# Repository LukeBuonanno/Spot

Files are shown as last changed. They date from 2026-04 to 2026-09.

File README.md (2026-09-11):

# ESP32-S3 Spotify Controller (GC9A01 Round TFT)

A handheld Spotify controller using an ESP32-S3, a 1.28" round GC9A01 TFT display, and a 4-button module, all housed in a 3D-printed chassis with a Windows 98–style interface.

## Notes

* This device controls Spotify playback but does not output audio
* Requires an active Spotify session on another device
* Spotify Premium is required for API playback control

## Hardware Requirements

* ESP32-S3 Dev Board
* 1.28" Round TFT LCD Display (240x240, GC9A01 driver)
* 4-bit Independent Button Module (micro switch board)
* Jumper wires
* 3D printed chassis
* USB cable for power and programming

Printables link: https://www.printables.com/model/1770463-spotify-controller-chassy

## Physical Assembly

### 1. Install the Display

* Press the round TFT display into the front ring of the chassis
* Ensure it sits flush and centered

### 2. Wire the Display (SPI)

Connect the display to the ESP32-S3 as follows:

| Display Pin | ESP32-S3 Pin |
| --- | --- |
| VCC | 3.3V |
| GND | GND |
| SCL (CLK) | GPIO 36 |
| SDA (MOSI)  | GPIO 35 |
| DC | GPIO 12 |
| CS | GPIO 14 |
| RST | GPIO 13 |

### 4. Wire the Button Module

The 4-button module typically has:

* VCC
* GND
* 4 signal outputs (one per button)

Connect as follows:

| Button Function | ESP32 Pin |
| --- | --- |
| Play/Pause | GPIO 4 |
| Mode/Menu | GPIO 5 |
| Previous | GPIO 6 |
| Next | GPIO 7 |

Then:

* Connect **GND on the module → ESP32 GND**
* If the module requires power:

  * Connect **VCC → 3.3V**

### 5. Final step: Install the ESP32-S3

* Insert the ESP32-S3 into the back of the chassis with pins facing inward.
* Connect USB power

## Software Setup

### 1. Install Arduino IDE

Install the latest Arduino IDE.

### 2. Install ESP32 Board Package

In Arduino IDE:

File → Preferences → Additional Board URLs:

https://raw.githubusercontent.com/espressif/arduino-esp32/gh-pages/package_esp32_index.json

Then:

* Open Boards Manager
* Install "ESP32 by Espressif Systems"

### 3. Select Board

* Board: ESP32S3 Dev Module
* Select the correct COM port

### 4. Install Required Libraries

Install these from Library Manager:

* ArduinoJson
* Adafruit GFX
* Adafruit GC9A01A

### 5. Add Project Files

Place these files in your project folder:

* micross7pt7b.h
* win98_clouds.h
* warning.h
* stop.h

## Spotify Setup

### 1. Create a Spotify App

Go to the Spotify Developer Dashboard and create an app.

You will get:

* Client ID
* Client Secret

### 2. Generate Refresh Token

Use OAuth with scopes:

user-read-playback-state
user-modify-playback-state

### 3. Insert Credentials

Update in your code:

String clientId = "YOUR_CLIENT_ID";
String clientSecret = "YOUR_CLIENT_SECRET";
String refreshToken = "YOUR_REFRESH_TOKEN";

## Uploading the Code

1. Connect ESP32-S3 via USB
2. Select correct board and port
3. Click Upload

If upload fails:

* Hold the BOOT button while uploading

## WiFi Setup
On first boot, the device creates a WiFi network:
Spotify-Controller-Setup

Join that network from your phone or laptop
Open: http://192.168.4.1

Input your WiFi name + password
Click Save and connect!

## Controls
(From left to right)
| Button | Action |
| --- | --- |
| Previous | Previous track |
| Next | Next track |
| Play | Play / Pause |
| Mode | Open playlist menu |

## Playlist Menu

* Previous / Next: Navigate playlists
* Play: Select playlist
* Mode: Exit menu

## Troubleshooting

### Screen not working

* Verify SPI wiring (SCL, SDA, CS, DC, RST)
* Confirm pins match code

### Spotify not responding

* Ensure a device is actively playing (phone, computer, etc.)
* Verify token and credentials

### Error screen appears

* No active Spotify device
* WiFi or API connection issue

### Buttons not working

* Check wiring from module outputs to GPIO pins
* Ensure GND is connected
* Confirm module logic matches pull-up configuration

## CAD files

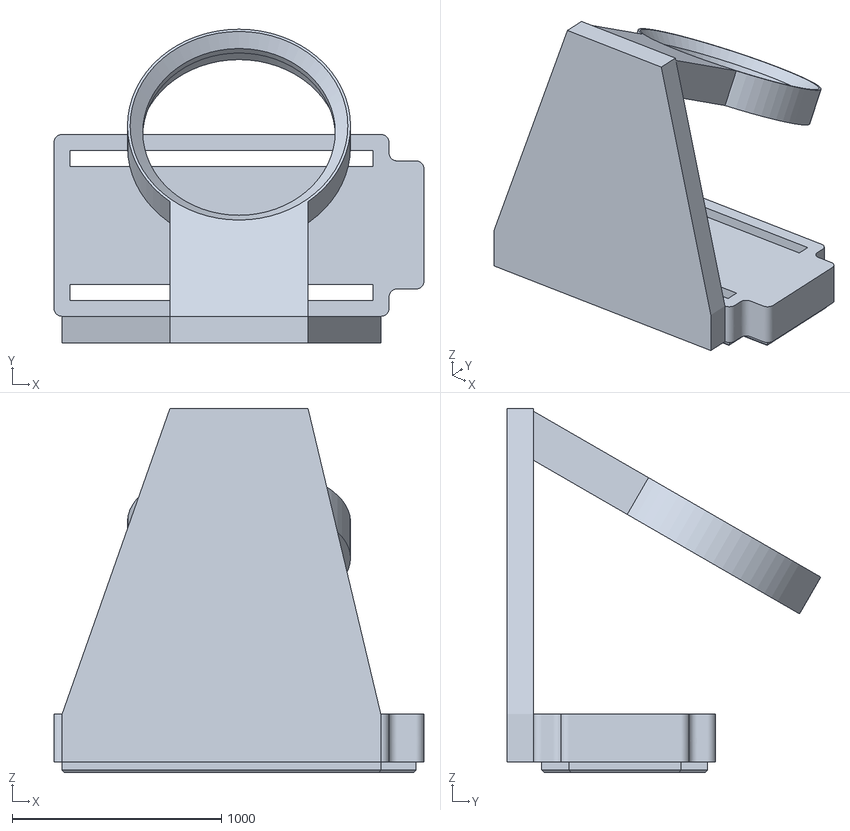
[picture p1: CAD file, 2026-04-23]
Spotify Dock.stl
1769.8 x 1500.2 x 1742.6

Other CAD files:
Spotify Dock.ipt

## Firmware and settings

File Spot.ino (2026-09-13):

#include <WiFi.h>
#include <WebServer.h>
#include <DNSServer.h>
#include <Preferences.h>
#include <WiFiClientSecure.h>
#include <HTTPClient.h>
#include <ArduinoJson.h>
#include <vector>
#include <SPI.h>
#include <Adafruit_GFX.h>
#include <Adafruit_GC9A01A.h>
#include "micross7pt7b.h"
#include "win98_clouds.h"
#include "warning.h"
#include "stop.h"

// ====== WiFi Configuration ======
// Credentials are stored permanently in ESP32 NVS using Preferences.
// The setup AP remains available while STA mode repeatedly attempts to connect.
const char* SETUP_AP_SSID = "Spotify-Controller-Setup";
const byte DNS_PORT = 53;
IPAddress setupIP(192, 168, 4, 1);

Preferences wifiPrefs;
WebServer setupServer(80);
DNSServer dnsServer;

String savedSSID = "";
String savedPassword = "";
bool wifiAttemptInProgress = false;
bool wifiWasConnected = false;
bool portalStarted = false;
unsigned long lastWifiRetry = 0;

// How long to let one WiFi.begin() attempt run before restarting it.
const unsigned long WIFI_CONNECT_TIMEOUT_MS = 15000;

// Small delay between failed attempts.
const unsigned long WIFI_RETRY_DELAY_MS = 1000;
const unsigned long WIFI_RETRY_MS = 5000;

// ====== Spotify ======
String clientId     = "CHANGEME";
String clientSecret = "CHANGEME";
String refreshToken = "CHANGEME";
String accessToken  = "";
String activeDeviceId = "";
bool isPaused  = false;
bool inMenu    = false;
int  selectedIndex = 0;

// ====== Spotify API ======
const char* spotifyAPI = "https://api.spotify.com/v1";

// ====== Buttons ======
#define BTN_MODE 5
#define BTN_PLAY 4
#define BTN_PV   6
#define BTN_NV   7

bool prevPVState   = HIGH, prevNVState   = HIGH;
bool prevPlayState = HIGH, prevModeState = HIGH;
const unsigned long LONG_PRESS_MS = 600;
const unsigned long DEBOUNCE_MS   = 50;
unsigned long lastPVAction = 0, lastNVAction = 0;
unsigned long lastPlayAction = 0, lastModeAction = 0;

// ====== Playlist ======
struct Playlist { String name; String uri; };
Playlist playlists[] = {
  {"CHANGEME (name)",       "spotify:playlist:CHANGEME"},
{"CHANGEME (name)",       "spotify:playlist:CHANGEME"},
{"CHANGEME (name)",       "spotify:playlist:CHANGEME"},
{"CHANGEME (name)",       "spotify:playlist:CHANGEME"}
};
const int NUM_PLAYLISTS = sizeof(playlists) / sizeof(playlists[0]);

// ====== TFT ======
#define TFT_MOSI 35
#define TFT_SCLK 36
#define TFT_DC   12
#define TFT_CS   14
#define TFT_RST  13
Adafruit_GC9A01A tft(TFT_CS, TFT_DC, TFT_MOSI, TFT_SCLK, TFT_RST);

inline void resetFont() {
  tft.setFont(&micross7pt7b);
  tft.setTextSize(1);
}

// ====== Win98 Color Palette ======
#define WIN98_BG     0xC618
#define WIN98_GRAY   0x9CF3
#define WIN98_DKGRAY 0x7BEF
#define WIN98_WHITE  0xFFFF
#define WIN98_BLACK  0x0000
#define WIN98_BLUE   0x001F
#define WIN98_TEXT   0x0000
#define WIN98_BORDER 0xFFFF
#define WIN98_SHADOW 0x7BEF

// ====== Window Geometry (shared constants) ======
// Keeping these as constants avoids recomputing them every draw call.
const int WIN_MARGIN   = 36;
const int WIN_TITLEBAR = 24;
const int WIN_X = WIN_MARGIN;
const int WIN_Y = WIN_MARGIN;
const int WIN_W = 240 - WIN_MARGIN * 2;   // 168
const int WIN_H = 240 - WIN_MARGIN * 2;   // 168

// ====== App State Machine ======
// These states gate both what runs in loop() AND what gets drawn to the screen.
// The screen only redraws when appState actually changes.
enum AppState {
  APP_WIFI_CONNECTING,  // STA is trying to reach the saved WiFi network
  APP_SPOTIFY_INIT,     // WiFi is up — getting token + devices
  APP_RUNNING           // fully operational, normal Spotify UI
};
AppState appState          = APP_WIFI_CONNECTING;
AppState lastDrawnAppState = (AppState)(-1);  // sentinel — forces first status draw

unsigned long lastSpotifyRetry = 0;
const unsigned long SPOTIFY_RETRY_MS = 5000;

// ====== Now Playing ======
struct NowPlaying {
  String track, artist;
  unsigned long progress_ms, duration_ms;
  bool isPlaying;
};
NowPlaying nowPlaying;

String lastTrack  = "";
String lastArtist = "";
unsigned long lastDuration = 0;
unsigned long lastProgress = 0;

// ====== Device / display state ======
bool deviceActive        = false;
bool brokenLinkDrawn     = false;
bool firstNowPlayingDraw = true;
unsigned long lastDeviceAttempt  = 0;
const unsigned long deviceRetryInterval = 5000;

// ====== Timing ======
unsigned long lastNowPlaying    = 0;
const unsigned long nowPlayingInterval = 2000;
unsigned long lastDisplayUpdate = 0;
const unsigned long displayInterval    = 150;
unsigned long lastTokenRefresh  = 0;
const unsigned long TOKEN_REFRESH_INTERVAL = 3500UL * 1000;

// ====== Display Constants ======
const int16_t DISP_W       = 240;
const int16_t DISP_H       = 240;
const int16_t BASE_TITLE_Y  = 60;
const int16_t BASE_ARTIST_Y = 90;

// ====== Forward Declarations ======
bool   refreshAccessToken();
void   fetchDevices();
void   fetchNowPlaying();
void   togglePlayPause();
void   nextTrack();
void   previousTrack();
void   playPlaylist(String uri);
void   checkButtons(unsigned long now);
void   displayNowPlaying(bool forceBG, bool forceGUI);
void   drawPlaylistMenu(bool fullRedraw, int prevIndex, int newIndex);
void   drawWin98WindowFrame(const char* title);
void   drawWin98CloudsBG();
void   drawBrokenLink(int16_t x, int16_t y);
void   drawWin98ProgressBar(unsigned long progress, unsigned long total, int y);
void   drawStatusWindow(const char* title, const char* line1, const char* line2 = "");
void   drawCenteredText(int16_t cx, int16_t cy, const char* text, uint16_t color, uint16_t bgColor);
void   drawCenteredTextBlock(int16_t cx, int16_t cy, const char* text, uint16_t color, uint16_t bgColor);
void   draw3DBorder(int x, int y, int w, int h);
void   drawWin98Button(int x, int y, int w, int h, const char* label, bool pressed = false);
void   drawWin98ButtonEx(int x, int y, int w, int h, const char* label, uint16_t bg, uint16_t textCol, bool pressed = false);
String trimString(const String& str);
int16_t getTextWidth(const String& text);
int16_t getTextHeight();
std::vector<String> wrapText(String text, int maxChars);
void loadWiFiCredentials();
void saveWiFiCredentials(const String& ssid, const String& password);
void startWiFiSetupPortal();
void handleWiFiSetupPortal();
void attemptWiFiConnection();
void handleWiFiConnection();
void setupPortalRoot();
void setupPortalSave();
void setupPortalNotFound();

// ====== Status Window ======
// Draw a Win98 window with one or two lines of centered status text.
// Touches only the window area — clouds behind it are never disturbed.
// Call this ONCE when entering a new state; it will NOT be called again
// until appState changes (enforced by the lastDrawnAppState guard in loop).
void drawStatusWindow(const char* title, const char* line1, const char* line2) {
  resetFont();
  drawWin98WindowFrame(title);  // fills WIN98_BG inside the window automatically
  if (strlen(line1) > 0)
    drawCenteredText(DISP_W / 2, DISP_H / 2 - 12, line1, WIN98_TEXT,   WIN98_BG);
  if (strlen(line2) > 0)
    drawCenteredText(DISP_W / 2, DISP_H / 2 + 10, line2, WIN98_DKGRAY, WIN98_BG);
}

// ====== WiFi Setup Captive Portal ======
String htmlEscape(const String& value) {
  String out;
  out.reserve(value.length() + 16);
  for (size_t i = 0; i < value.length(); i++) {
    char c = value[i];
    if (c == '&') out += F("&amp;");
    else if (c == '<') out += F("&lt;");
    else if (c == '>') out += F("&gt;");
    else if (c == '"') out += F("&quot;");
    else out += c;
  }
  return out;
}

void loadWiFiCredentials() {
  wifiPrefs.begin("wifi", true);
  savedSSID = wifiPrefs.getString("ssid", "");
  savedPassword = wifiPrefs.getString("password", "");
  wifiPrefs.end();

  Serial.println("Stored WiFi SSID: " + (savedSSID.length() ? savedSSID : String("<none>")));
}

void saveWiFiCredentials(const String& ssid, const String& password) {
  wifiPrefs.begin("wifi", false);
  wifiPrefs.putString("ssid", ssid);
  wifiPrefs.putString("password", password);
  wifiPrefs.end();

  savedSSID = ssid;
  savedPassword = password;
  Serial.println("Saved WiFi credentials for: " + savedSSID);
}

void setupPortalRoot() {
  String page = F(R"HTML(
<!doctype html>
<html>
<head>
<meta name="viewport" content="width=device-width,initial-scale=1">
<title>Spotify Controller WiFi</title>
<style>
body{font-family:Arial,sans-serif;background:#c0c0c0;margin:0;padding:20px;color:#000}
.window{max-width:420px;margin:20px auto;background:#c0c0c0;border:2px solid #fff;box-shadow:2px 2px #000}
.title{background:#000080;color:#fff;font-weight:bold;padding:8px}
.content{padding:18px}
label{display:block;margin:12px 0 5px;font-weight:bold}
input{box-sizing:border-box;width:100%;padding:10px;border:2px inset #fff;background:#fff}
button{margin-top:18px;padding:10px 18px;font-weight:bold}
.status{padding:10px;background:#eee;border:1px solid #777;margin-bottom:14px}
.small{font-size:13px;color:#333}
</style>
</head>
<body>
<div class="window">
<div class="title">Spotify Controller - WiFi Setup</div>
<div class="content">
<div class="status">The controller will keep trying to connect to WiFi in the background. This setup page stays available while it does so.</div>
<form method="POST" action="/save">
<label for="ssid">WiFi network (SSID)</label>
<input id="ssid" name="ssid" type="text" maxlength="64" required value=")HTML");
  page += htmlEscape(savedSSID);
  page += F(R"HTML(">
<label for="password">WiFi password</label>
<input id="password" name="password" type="password" maxlength="128" value=")HTML");
  page += htmlEscape(savedPassword);
  page += F(R"HTML(">
<button type="submit">Save and connect</button>
</form>
<p class="small">Setup address: 192.168.4.1</p>
</div>
</div>
</body>
</html>
)HTML");

  setupServer.send(200, "text/html", page);
}

void setupPortalSave() {
  String ssid = setupServer.arg("ssid");
  String password = setupServer.arg("password");
  ssid.trim();

  if (ssid.length() == 0) {
    setupServer.send(400, "text/plain", "SSID cannot be empty.");
    return;
  }

  saveWiFiCredentials(ssid, password);

  setupServer.send(200, "text/html", R"HTML(
<!doctype html><html><head><meta name="viewport" content="width=device-width,initial-scale=1">
<title>Saved</title></head><body style="font-family:Arial;padding:25px">
<h2>WiFi saved</h2><p>The ESP32 is now trying to connect to the new network.</p>
<p>You can leave this page open. The setup portal will remain available.</p>
</body></html>)HTML");

  // Start a fresh STA connection without erasing the newly saved credentials.
  wifiWasConnected = false;
  wifiAttemptInProgress = false;
  WiFi.disconnect(false, false);
  delay(50);
  attemptWiFiConnection();
}

void setupPortalNotFound() {
  // Captive portal behavior: send unknown URLs back to the configuration page.
  setupServer.sendHeader("Location", String("http://") + setupIP.toString(), true);
  setupServer.send(302, "text/plain", "Redirecting to WiFi setup...");
}

void startWiFiSetupPortal() {
  if (portalStarted) return;

  // AP+STA lets the ESP32 host the setup page while simultaneously trying WiFi.
  // The AP is stopped automatically once the STA connection succeeds.
  WiFi.mode(WIFI_AP_STA);
  WiFi.softAPConfig(setupIP, setupIP, IPAddress(255, 255, 255, 0));
  WiFi.softAP(SETUP_AP_SSID);

  dnsServer.start(DNS_PORT, "*", setupIP);

  setupServer.on("/", HTTP_GET, setupPortalRoot);
  setupServer.on("/save", HTTP_POST, setupPortalSave);

  // Common captive-portal probe URLs used by phones/computers.
  setupServer.on("/generate_204", HTTP_ANY, setupPortalRoot);
  setupServer.on("/hotspot-detect.html", HTTP_ANY, setupPortalRoot);
  setupServer.on("/connecttest.txt", HTTP_ANY, setupPortalRoot);
  setupServer.on("/ncsi.txt", HTTP_ANY, setupPortalRoot);
  setupServer.onNotFound(setupPortalNotFound);
  setupServer.begin();

  portalStarted = true;

  Serial.println("WiFi setup AP started: " + String(SETUP_AP_SSID));
  Serial.println("Connect to it and open http://192.168.4.1/");
}

void handleWiFiSetupPortal() {
  if (!portalStarted) return;
  dnsServer.processNextRequest();
  setupServer.handleClient();
}

void stopWiFiSetupPortal() {
  if (!portalStarted) return;

  Serial.println("WiFi connected. Stopping setup portal.");

  dnsServer.stop();
  setupServer.stop();
  WiFi.softAPdisconnect(true);

  // Leave the ESP32 in normal station mode now that configuration is complete.
  WiFi.mode(WIFI_STA);
  portalStarted = false;
}

void attemptWiFiConnection() {
  if (savedSSID.length() == 0) {
    Serial.println("No saved WiFi credentials. Waiting for setup portal.");
    wifiAttemptInProgress = false;
    return;
  }

  // Never call WiFi.begin() while another connection attempt is active.
  if (wifiAttemptInProgress) {
    return;
  }

  Serial.println("Trying WiFi: " + savedSSID);

  // Make sure we're in AP+STA mode so the setup portal stays alive.
  WiFi.mode(WIFI_AP_STA);

  // Start exactly one connection attempt.
  WiFi.begin(savedSSID.c_str(), savedPassword.c_str());

  wifiAttemptInProgress = true;
  lastWifiRetry = millis();
}


void handleWiFiConnection() {
  unsigned long now = millis();
  wl_status_t status = WiFi.status();

  if (status == WL_CONNECTED) {
    if (!wifiWasConnected) {
      wifiWasConnected = true;
      wifiAttemptInProgress = false;

      Serial.println("WiFi connected: " + WiFi.localIP().toString());

      // Connection succeeded, so the setup AP is no longer needed.
      stopWiFiSetupPortal();

      appState = APP_SPOTIFY_INIT;
      lastSpotifyRetry = 0;
    }

    return;
  }

  if (wifiAttemptInProgress &&
      now - lastWifiRetry >= WIFI_CONNECT_TIMEOUT_MS) {

    Serial.println("WiFi connection timed out. Retrying...");

    // Abort the current STA connection cleanly.
    WiFi.disconnect(false, false);

    wifiAttemptInProgress = false;
    lastWifiRetry = now;
  }

  if (wifiWasConnected) {
    Serial.println("WiFi connection lost. Restarting setup portal and retrying.");

    wifiWasConnected = false;
    wifiAttemptInProgress = false;

    appState = APP_WIFI_CONNECTING;
    lastDrawnAppState = (AppState)(-1);

    startWiFiSetupPortal();

    return;
  }

  if (!wifiAttemptInProgress &&
      now - lastWifiRetry >= WIFI_RETRY_DELAY_MS) {

    attemptWiFiConnection();
  }
}

// ====== Setup ======
// Initialise display first so we can show status immediately, then kick off
// WiFi non-blocking.  Everything else is handled by the state machine in loop().
void setup() {
  Serial.begin(115200);
  delay(200);

  pinMode(BTN_PLAY, INPUT_PULLUP);
  pinMode(BTN_MODE, INPUT_PULLUP);
  pinMode(BTN_PV,   INPUT_PULLUP);
  pinMode(BTN_NV,   INPUT_PULLUP);

  // ── Display first ──────────────────────────────────────────────────────
  tft.begin();
  tft.setRotation(0);
  tft.fillScreen(0x0000);
  resetFont();
  drawWin98CloudsBG();   // ← THE ONLY PLACE THIS IS EVER CALLED
                         //   Clouds are permanent wallpaper; never redrawn.

  // ── WiFi setup / connection ───────────────────────────────────────────
  loadWiFiCredentials();
  startWiFiSetupPortal();
  attemptWiFiConnection();
  // loop() handles retries and the captive portal without blocking.
}

// ====== Loop ======
void loop() {
  unsigned long now = millis();

  // ════════════════════════════════════════════════════════════════════════
  // WiFi setup portal + background connection state machine
  // The portal is serviced while STA mode is disconnected/reconnecting.
  // Once WiFi connects, the portal/AP is shut down automatically.
  // ════════════════════════════════════════════════════════════════════════
  handleWiFiSetupPortal();
  handleWiFiConnection();

  switch (appState) {
    case APP_WIFI_CONNECTING: {
      if (lastDrawnAppState != appState) {
        drawStatusWindow("WiFi",
                         savedSSID.length() ? savedSSID.c_str() : "No WiFi saved",
                         "Wifi: Spotify-Controller");
        lastDrawnAppState = appState;
      }
      return;
    }

    case APP_SPOTIFY_INIT: {
      if (lastDrawnAppState != appState) {
        drawStatusWindow("Connecting...", "Spotify...", "");
        lastDrawnAppState = appState;
        lastSpotifyRetry = 0;
      }

      if (WiFi.status() != WL_CONNECTED) {
        appState = APP_WIFI_CONNECTING;
        lastDrawnAppState = (AppState)(-1);
        return;
      }

      if (now - lastSpotifyRetry >= SPOTIFY_RETRY_MS) {
        lastSpotifyRetry = now;
        if (refreshAccessToken()) {
          lastTokenRefresh = now;

          // Get the device and current playback state before entering the
          // normal UI. This prevents the first frame from being drawn with
          // an empty nowPlaying object and then immediately being replaced.
          fetchDevices();
          if (deviceActive) {
            fetchNowPlaying();
            lastNowPlaying = now;
          }

          appState = APP_RUNNING;
          lastDrawnAppState = (AppState)(-1);
          firstNowPlayingDraw = true;
        }
      }
      return;
    }

    case APP_RUNNING:
    default:
      break;
  }

  // ── WiFi watchdog while running ─────────────────────────────────────────
  // handleWiFiConnection() above starts retries and enables the setup
  // AP again if the network disappears.
  if (WiFi.status() != WL_CONNECTED) {
    appState = APP_WIFI_CONNECTING;
    lastDrawnAppState = (AppState)(-1);
    deviceActive = false;
    return;
  }

  // ── Periodic token refresh ──────────────────────────────────────────────
  if (now - lastTokenRefresh > TOKEN_REFRESH_INTERVAL) {
    if (refreshAccessToken()) lastTokenRefresh = now;
  }

  // ── Device heartbeat ────────────────────────────────────────────────────
  // Keep polling even while a device is currently active. Spotify can go from
  // an active session to no active session without changing WiFi state, so we
  // must re-check /me/player/devices periodically to detect that transition.
  if (now - lastDeviceAttempt > deviceRetryInterval) {
    bool wasDeviceActive = deviceActive;

    fetchDevices();
    lastDeviceAttempt = now;

    if (!deviceActive) {
      // No active Spotify session: show the error exactly once.
      if (!brokenLinkDrawn) {
        drawBrokenLink(0, 0);
        brokenLinkDrawn = true;
      }
    } else if (!wasDeviceActive) {
      // Spotify session returned: fetch the current track before drawing the
      // normal UI so we do not flash an empty Now Playing screen.
      brokenLinkDrawn = false;
      fetchNowPlaying();
      lastNowPlaying = now;
      firstNowPlayingDraw = true;
    }
  }

  checkButtons(now);

  // ── Now Playing refresh + display ───────────────────────────────────────
  if (deviceActive && !inMenu) {
    if (now - lastNowPlaying > nowPlayingInterval) {
      fetchNowPlaying();
      lastNowPlaying = now;
    }
    if (now - lastDisplayUpdate > displayInterval) {
      if (firstNowPlayingDraw) {
        displayNowPlaying(true, true);
        firstNowPlayingDraw = false;
      } else {
        displayNowPlaying(false, false);
      }
      lastDisplayUpdate = now;
    }
  }
}

// ====== Spotify API Functions ======
bool refreshAccessToken() {
  HTTPClient http;
  http.begin("https://accounts.spotify.com/api/token");
  http.addHeader("Content-Type", "application/x-www-form-urlencoded");
  String body = "grant_type=refresh_token&refresh_token=" + refreshToken +
                "&client_id=" + clientId + "&client_secret=" + clientSecret;
  int code = http.POST(body);
  if (code == 200) {
    DynamicJsonDocument doc(1024);
    deserializeJson(doc, http.getString());
    accessToken = doc["access_token"].as<String>();
    Serial.println("New access token acquired!");
    http.end();
    return true;
  }
  Serial.printf("Token refresh failed: %d\n", code);
  http.end();
  return false;
}

void fetchDevices() {
  if (accessToken == "") return;

  HTTPClient http;
  http.begin(String(spotifyAPI) + "/me/player/devices");
  http.addHeader("Authorization", "Bearer " + accessToken);

  int code = http.GET();
  bool found = false;
  String foundDeviceId = "";

  if (code == 200) {
    DynamicJsonDocument doc(8192);
    deserializeJson(doc, http.getString());
    JsonArray devices = doc["devices"].as<JsonArray>();

    // /me/player/devices returns available Connect devices, not necessarily
    // the device with the current Spotify session. Only is_active=true should
    // count as an active session for this controller.
    for (JsonObject device : devices) {
      if (device["is_active"] == true) {
        foundDeviceId = device["id"].as<String>();
        Serial.println("Active Device: " + foundDeviceId);
        found = true;
        break;
      }
    }

    if (!found) {
      Serial.println("No active Spotify devices found!");
    }
  } else {
    Serial.printf("fetchDevices() failed: %d\n", code);
  }

  deviceActive = found;
  if (found) {
    activeDeviceId = foundDeviceId;
  } else {
    activeDeviceId = "";
    nowPlaying.track = "";
    nowPlaying.artist = "";
    nowPlaying.progress_ms = 0;
    nowPlaying.duration_ms = 0;
    nowPlaying.isPlaying = false;
  }

  http.end();
}
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

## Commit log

2026-04-23 setting up repo
    [Spotify Dock.ipt, Spotify Dock.stl]
2026-07-02 Add Printables link for Spotify controller chassis
2026-09-10 fixed all redraw jank
    [Spot.ino]
2026-09-10 Improve device management and session handling
    Refactor device polling logic to handle transitions between active and inactive Spotify sessions. Update fetchDevices function to correctly identify active devices.
    [Spot.ino]
